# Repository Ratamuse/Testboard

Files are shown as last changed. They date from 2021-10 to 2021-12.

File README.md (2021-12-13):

## Testboard V2.2 ESP32

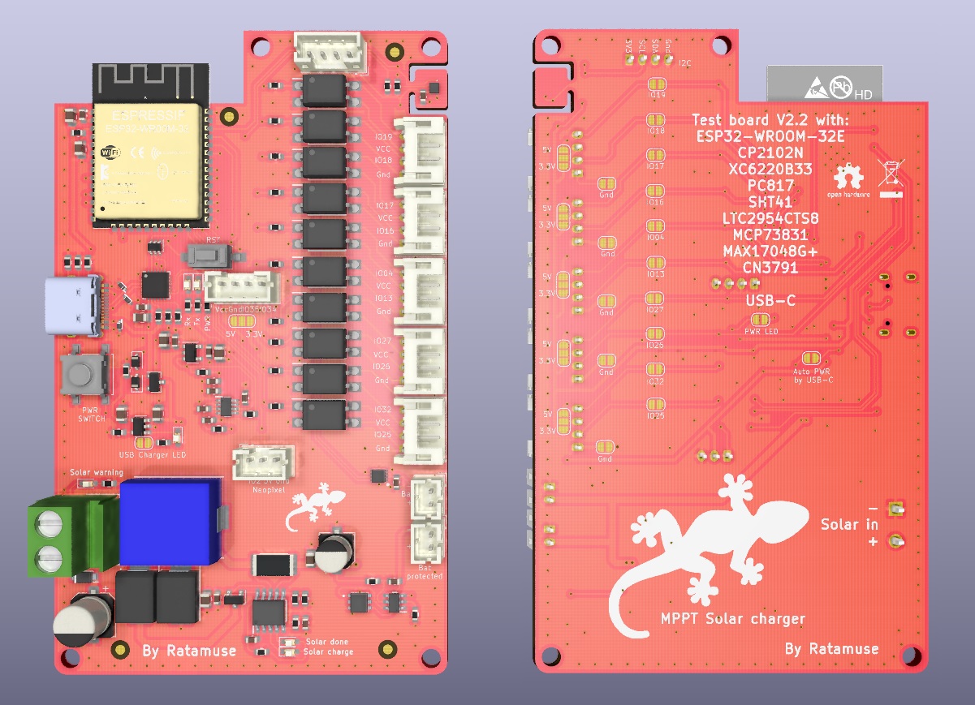
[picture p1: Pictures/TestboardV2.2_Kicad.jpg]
This is an image


## Carte multi-usage basée sur le module ESP-WROOM-32E:

- Connecteur USB-C

- Chargeur solaire MPPT basé sur la puce CN3791:  http://www.consonance-elec.com/pdf/datasheet/DSE-CN3791.pdf

- Connecteur batterie JST-PH 2mm avec protection (surcharge ou décharge profonde)

- Connecteur batterie JST-PH 2mm sans protection (pour batterie déjà protégée)

- Bouton on/off LTC2954 avec interrupt sur µP (On/Off de l'ESP32 et GPIO de l'interrupt utilisable pour des actions): https://www.analog.com/media/en/technical-documentation/data-sheets/2954fb.pdf

- Capteur température/humidité SHT41: https://www.sensirion.com/fileadmin/user_upload/customers/sensirion/Dokumente/2_Humidity_Sensors/Datasheets/Sensirion_Humidity_Sensors_SHT4x_Datasheet.pdf
- 10 optocoupleurs pour interrupteurs à contacts secs (pour domotiser volets roulants, télécommandes diverses) ou au choix 10 GPIO dispo avec au choix alim 3.3V ou "5V" (Vbat (entre 3.2 et 4.2V) ou Vbus (5V)) pour ajouter des modules.

- Chargeur Li-io/Li-Po MCP73831 via port USB-C

- Connecteur JST-PH 2mm (1x4) I2C

- Connecteur JST-PH 2mm (1x4) sur 2 GPIO + choix 3.3V ou 5V

- Connecteur JST-PH 2mm (1x3) sur 1 GPIO (que j'utilise pour piloter des leds neopixel)

Inspiration des travaux de Lilygo, Waveshare, GreatScoot.

Motivation et champs des possibles donnés par P. Demerliac et sa chaine Youtube Cyrob: https://www.youtube.com/channel/UC5QPFDZ3Y4ylkkGJc6Y1OOA  

Initiation à la bricole par P. W. Trainer

Prochaine étape, améliorer le hardaware du GNUVario-E

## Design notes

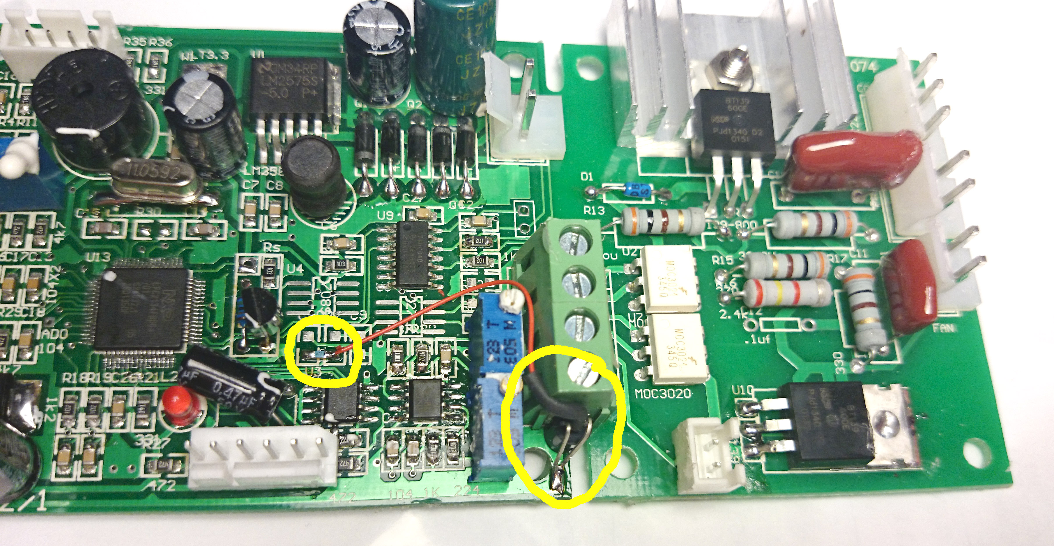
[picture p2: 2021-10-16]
3D/tempsensor-mod.jpg

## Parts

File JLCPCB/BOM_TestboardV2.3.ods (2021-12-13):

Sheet: TestboardV2.2
Id | Référence | Boîtier | Quantit� | Désignation | Mouser | LCSC | Reste | Quantité | A commander
1 | J13 | TYPE-C-31-M-12 | 1 | USB_C_Receptacle_USB2.0 USB4105-GF-A | 640-USB4105-GF-A |  | 2 | 1 | 2 | VMPTT | 18
2 | D14,D4 | D_SOD-323 | 2 | D_Schottky | 757-CUS10F30H3F or BAT20JFILM |  | 6 | 2 | 4 | R3
3 | R28 | R_2512_6332Metric | 1 | 0,05 | 71-WSL2512R2200FEA |  | 2 | 1 |  | R4 | 10000
4 | R23 | R_0603_1608Metric | 1 | 120K | 660-RN73H1JTD1203B25 |  | 3 | 2
5 | R23 | R_0603_1608Metric | 1 | 140K | 660-RK73H1JTTD1403F |  | 9
6 | C26 | CP_Elec_5x5.4 | 1 | 10µF/35V | 667-EEE-1VA100SR |  | 22 | 1 |  | VMPPT=1,205x(1+R3/R4)
7 | L1 | INDPM138126X700N | 1 | 82µH/3A |  | C149533 | 12 | 1
8 | Q4 | FS8205 | 1 | FS8205 |  | C32254 | 7 | 1
9 | D7,D6,D5,D9,D10,D13, D15 | LED_0603_1608Metric_Castellated | 7 | LED | 720-LSQ976-NR-1 & 720-LTQ39GQ1S22515 & 720-KODELLS122A4850 |  | 9R, 4V, 6O | 7 |  | VMPPT/1,205-1=R3/R4
10 | R22,R21,R14,R11,R10,R9,R8,R7,R6,R5,R4,R3,R2,R30,R29 | R_0603_1608Metric | 15 | 1K | 279-CRGCQ0603F1K0 |  | 46 | 15
11 | C3,C1 | C_0805_2012Metric | 2 | 22µF | 81-GRM219R61C226ME1K |  | 14 | 2 |  | (VMPPT/1,205-1)xR4
12 | D3,D2,D1 | SODFL1406X65N | 3 | SP1003-01DTG | 576-SP1003-01DTG |  | 5 | 3
13 | U12 | QFN-24-1EP_4x4mm_P0.5mm_EP2.6x2.6mm | 1 | CP2102N-A02-GQFN24 | 634-CP2102NA02QFN24R |  | 2 | 1 |  | #RÉF !
14 | IC2 | SON50P200X200X80-9N-D | 1 | MAX17048G+ | 700-MAX17048G+T10 |  | 24 | 1
15 | U1 | ESP32WROOM32EM113EH2800PH3Q0 | 1 | ESP32-WROOM-32E | 356-ESP32WRM32E128PH |  | 8 | 1
16 | C18,C12,C11,C9,C7,C2,C5,C27, C15 | C_0603_1608Metric | 9 | 0.1µF | 81-GCJ188R71C104KA1D |  | 41 | 10
17 | Q1 | SOT-363_SC-70-6 | 1 | UMH3N | 755-UMH3NTN |  | 7 | 1
18 | R17,R16 | R_0603_1608Metric | 2 | 2.2K | 279-CRGCQ0603F2K2 |  | 77 | 2
19 | IC1 | BME680 | 1 | BME680 | 262-BME680 |  | 0 | 1
20 | C13,C4 | C_0603_1608Metric | 2 | 1µF | 81-GCM188R71C105KA4J |  | 28 | 2
21 | U11,U10,U9,U8,U7,U6,U5,U4,U3,U2 | SOP254P960X420-4N | 10 | PC817 | 852-PC81710NIP1B |  | 8 | 10
22 | SW1,SW4 | PTS636SL43SMTRLFS | 2 | SW_Push | 611-PTS636SL43SMTRLF |  | 6 | 2
23 | R13 | R_0603_1608Metric | 1 | 47.5k | 755-SFR03EZPF4752 |  | 5 | 1
24 | R12 | R_0603_1608Metric | 1 | 22.1K | 660-RK73H1JTTDD2212F |  | 5 | 1
25 | R1,R19,R15,R27 | R_0603_1608Metric | 4 | 10K | 660-RN73H1JT1002F100 |  | 8 | 3
26 | U13 | SOT-23-5 | 1 | XC6220B331MR | 865-XC6220B331MR-G |  |  | 1
27 | C6,C16,C17 | C_0805Metric | 3 | 4.7µF | 81-GCM21BR71C475KA3L |  | 11 | 3
28 | Q2 | SOT-23 | 1 | DMG2301L | 621-DMG2301L-7 |  | ? | 1
29 | R18,R25,R35 | R_0603_1608Metric | 3 | 2K | 71-RCS06032K00FKEA |  | 12 | 3
30 | R20 | R_0603_1608Metric | 1 | 330 | 603-RE0603FRE07330RL |  | 11 | 1
31 | U15 | SOT-23-5 | 1 | MCP73831-2-OT | hors stock |  | 10 | 1
32 | C8,C10 | C_0603_1608Metric | 2 | 0,150µF | 80-C0603C154J4R |  | 4 | 2
33 | C8,C10 | C_0603_1608Metric | 2 | 0,330µF | 80-C0603C334J4R |  | 10
34 | C19 | CP_Elec_6.3x7.7 | 1 | 100µF/35V | 667-EEE-1VA101UP |  | 1 | 1
35 | C22 | C_0603_1608Metric | 1 | 220nF | 81-GCM188R71H224KA4J |  | 6 | 1
36 | C25 | C_0805_2012Metric | 1 | 10µF | 81-GCM21BM8EE106KE8L |  | 4 | 1
37 | D8 | SODFL3616X98N | 1 | MBR230LSFT1G | 755-RB060MM-30TFTR |  | 2 | 1
38 | D11,D12 | DIOM8059X256N | 2 | SS34 |  |  | 4 | 2
39 | IC3 | SOT65P280X100-8N | 1 | LTC2954CTS8-1#TRMPBF | 584-C2954CTS8-1TMPF |  | 3 | 1
40 | IC4 | SOP100P600X175-10N | 1 | CN3791 |  | C154992 | 10 | 1
41 | Q3 | SOT-23 | 1 | AO3401A |  | C306862 | 25 | 1
42 | Q5 | SOT95P280X125-3N | 1 | AO3400 |  | C332101 | 8 | 1
43 | R24 | R_0603_1608Metric | 1 | 120 | 660-RN73H1JT1200D100 |  | 2 | 1
44 | R31 | R_0603_1608Metric | 1 | 100 | 660-RN73H1JTD1000F25 |  | 2 | 1
45 | R32 | R_0603_1608Metric | 1 | 1.2K | 660-RN73H1JTD1201B25 |  | 2 | 1
46 | SW2 | SW_SPST_B3S-1000 | 1 | SW_Push | 653-B3S-1000 |  | 4 | 1
47 | C14 | C_0603_1608Metric | 1 | 470nF/50V | 810-C1608X7R1H474K |  | 7 | 1
48 | IC5 | SOT95P280X145-6N | 1 | FS312F-G |  | C82736 | 7 | 1
49 | R26 | R_0603_1608Metric | 1 | 1M | 755-KTR03EZPJ105 |  | 2 | 1
50 | R33,R34, R36 | R_0603_1608Metric | 3 | 5.1K | 660-RN73H1JTD5101B25 |  | 5 | 3
51 | R36 bis | R_0603_1608Metric | 1 | 0R | 71-RCS06030000Z0EA |  | 10 | 1
52 | C21 | C_0805Metric | 1 | 4,7µF/50V | 81-GRT21BR61H475KE3L |  | 2
53 | C23 | C_0603_1608Metric | 1 | 0,1µF/50V | 81-GCJ188R71H104KA2D |  | 7
54 | R37 | R_0603_1608Metric | 1 | 100K | 660-RN73H1JT1200D100 |  |  | 1

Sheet: TestboardV2.2_2
 | Id | Référence | Boîtier | Quantit� | Désignation | Mouser | Open PNP | LCSC | Reste | Quantité | DIGIKEY
1 | 16 | C18,C12,C11,C9,C7,C2,C5,C27, C15 | C_0603_1608Metric | 9 | 0.1µF | 81-GCJ188R71C104KA1D | ok |  | 41 | 10
2 | 20 | C13,C4 | C_0603_1608Metric | 2 | 1µF | 81-GCM188R71C105KA4J | ok |  | 28 | 2
3 | 35 | C22 | C_0603_1608Metric | 1 | 220nF/50V | 81-GCM188R71H224KA4J | ok |  | 6 | 1
4 | 47 | C14 | C_0603_1608Metric | 1 | 470nF/50V | 810-C1608X7R1H474K | ok |  | 7 | 1 |  | (VMPPT/1,205-1)xR4
5 | 50 | R33,R34, R36 | R_0603_1608Metric | 3 | 5.1K | 660-RN73H1JTD5101B25 | ok |  | 5 | 3
6 | 49 | R26 | R_0603_1608Metric | 1 | 1M | 755-KTR03EZPJ105 | ok |  | 2 | 1
7 | 30 | R20 | R_0603_1608Metric | 1 | 330 | 603-RE0603FRE07330RL | ok |  | 1 | 1
8 | 44 | R31 | R_0603_1608Metric | 1 | 100 | 660-RN73H1JTD1000F25 | ok |  | 2 | 1
9 | 45 | R32 | R_0603_1608Metric | 1 | 1.2K | 660-RN73H1JTD1201B25 | ok |  | 2 | 1
10 | 10 | R22,R21,R14,R11,R10,R9,R8,R7,R6,R5,R4,R3,R2,R30 | R_0603_1608Metric | 14 | 1K | 279-CRGCQ0603F1K0 | ok |  | 46 | 15
11 | 18 | R17,R16 | R_0603_1608Metric | 2 | 2.2K | 279-CRGCQ0603F2K2 | ok |  | 77 | 2
12 | 23 | R13 | R_0603_1608Metric | 1 | 47.5k | 755-SFR03EZPF4752 | ok |  | 5 | 1
13 | 24 | R12 | R_0603_1608Metric | 1 | 22.1K | 660-RK73H1JTTDD2212F | ok |  | 5 | 1
14 | 25 | R1,R19,R15,R27,R29,R25,R35 | R_0603_1608Metric | 5 | 10K | 660-RN73H1JT1002F100 | ok |  | 8 | 3
15 | 29 | R18 | R_0603_1608Metric | 1 | 2K | 71-RCS06032K00FKEA | ok |  | 1 | 1
16 | 53 | C23 | C_0603_1608Metric | 1 | 0,1µF/50V | 81-GCJ188R71H104KA2D |  |  | 7
17 | 32 | C8,C10 | C_0603_1608Metric | 2 | 0,150µF | 80-C0603C154J4R |  |  | 4
18 | 26 | U13 | SOT-23-5 | 1 | XC6220B331MR | 865-XC6220B331MR-G |  |  |  | 1 | 893-1133-1-ND
19 | 39 | IC3 | SOT65P280X100-8N | 1 | LTC2954CTS8-1#TRMPBF | 584-C2954CTS8-1TMPF |  |  |  | 1
 |  | GRM188R61C106KAALD |  | 0.800 | id R0603 | 100.0%

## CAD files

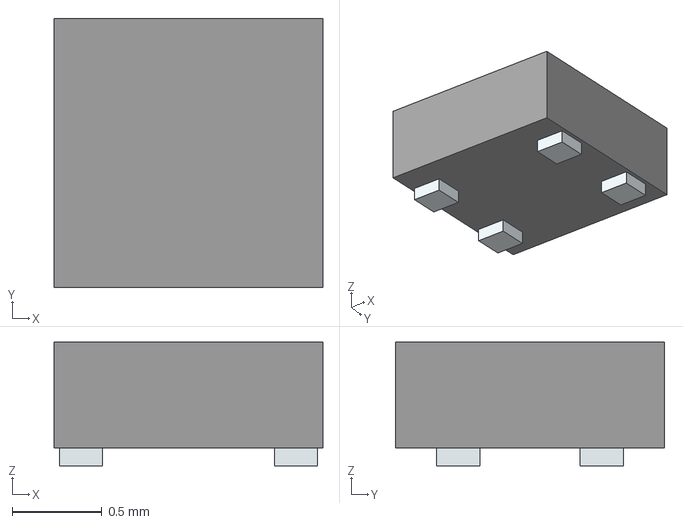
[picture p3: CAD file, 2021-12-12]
3D/SHT41-AD1B-R3.stp
1.50 x 1.50 x 0.69 mm
Pins

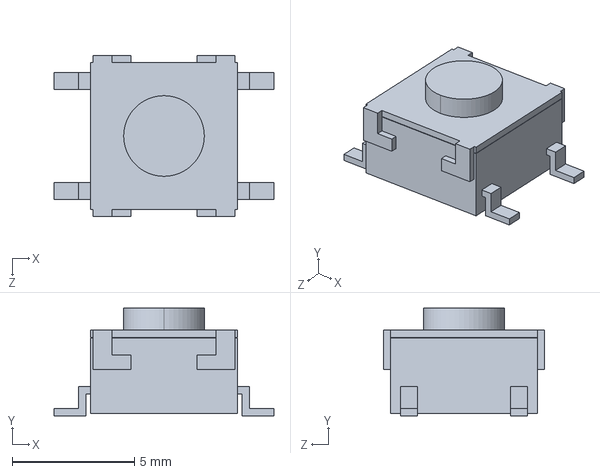
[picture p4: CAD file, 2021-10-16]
3D/B3S_100[].step
9.00 x 4.40 x 6.60 mm

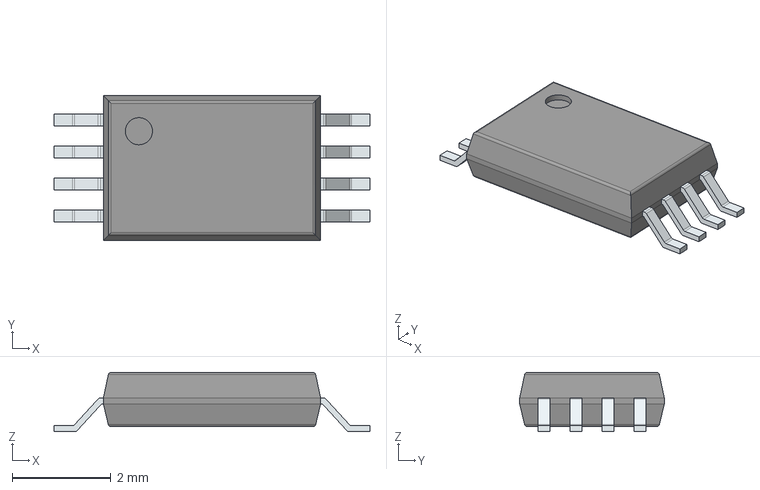
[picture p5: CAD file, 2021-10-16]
3D/FS8205A.stp
6.40 x 2.93 x 1.20 mm
PinsArrayLR

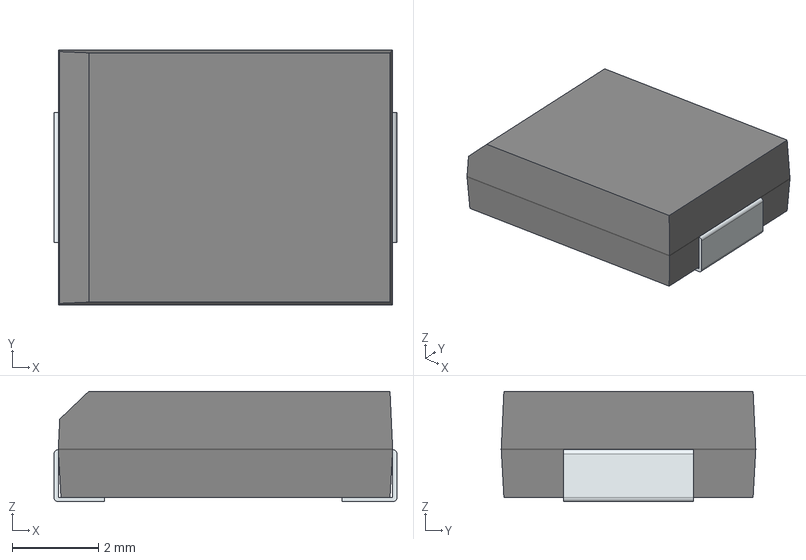
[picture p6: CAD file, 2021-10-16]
3D/SS34.stp
7.95 x 5.90 x 2.56 mm
FilletPin1
FilletPin2

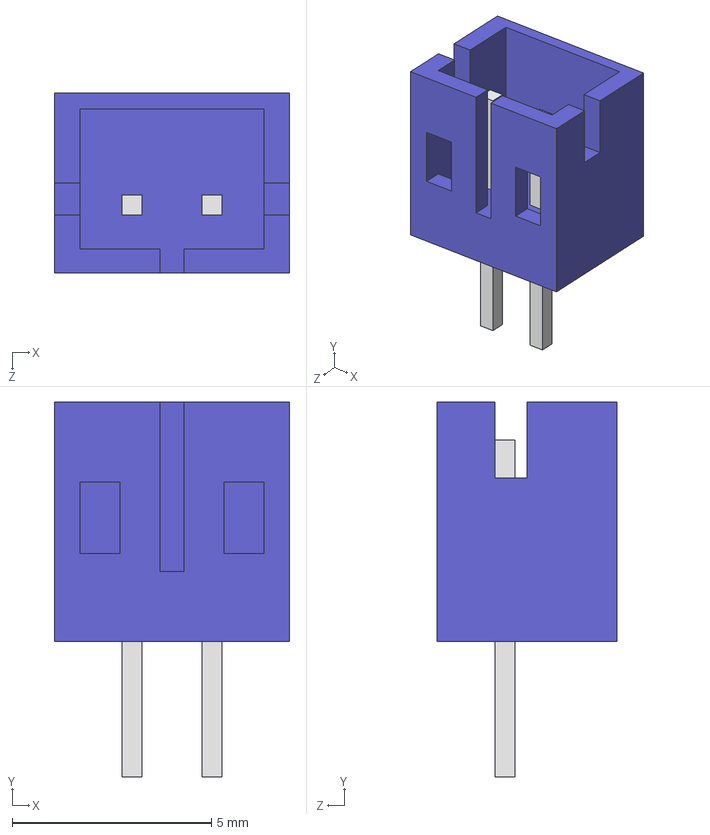
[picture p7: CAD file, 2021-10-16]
3D/B2B-PH-K-S.STEP
5.90 x 9.40 x 4.50 mm

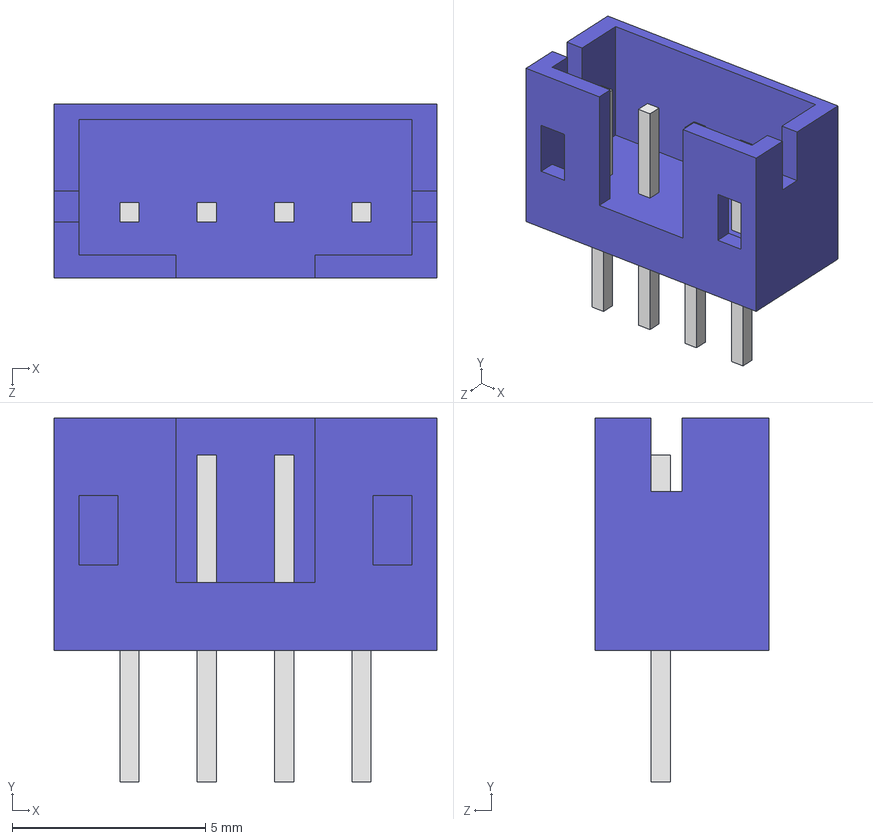
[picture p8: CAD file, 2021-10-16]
3D/B4B-PH-K-S.STEP
9.90 x 9.40 x 4.50 mm

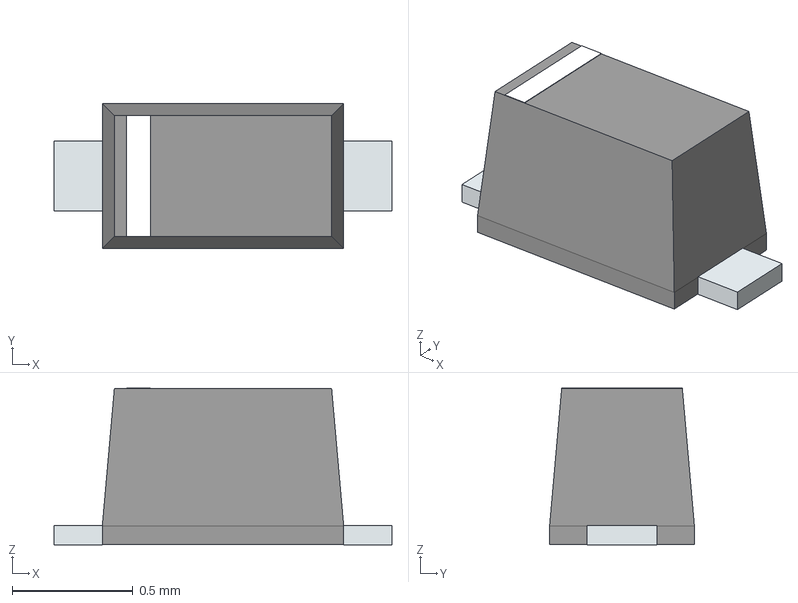
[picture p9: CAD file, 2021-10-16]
3D/SP1003-01DTG.stp
1.40 x 0.6 x 0.65 mm
PinKIdent
PinK
PinA

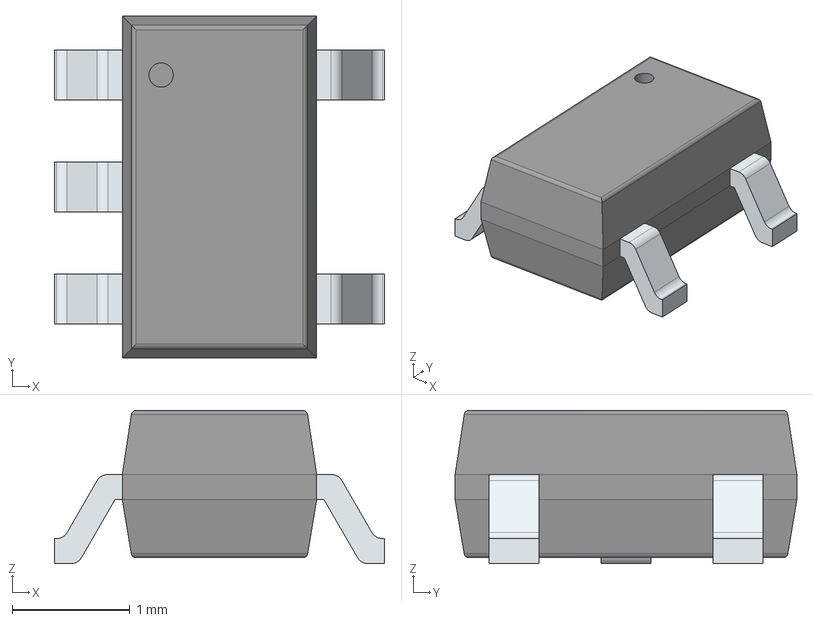
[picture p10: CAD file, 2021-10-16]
3D/XC6220B331MR-G.stp
2.80 x 2.90 x 1.30 mm
PinsArrayL
PinsArrayR

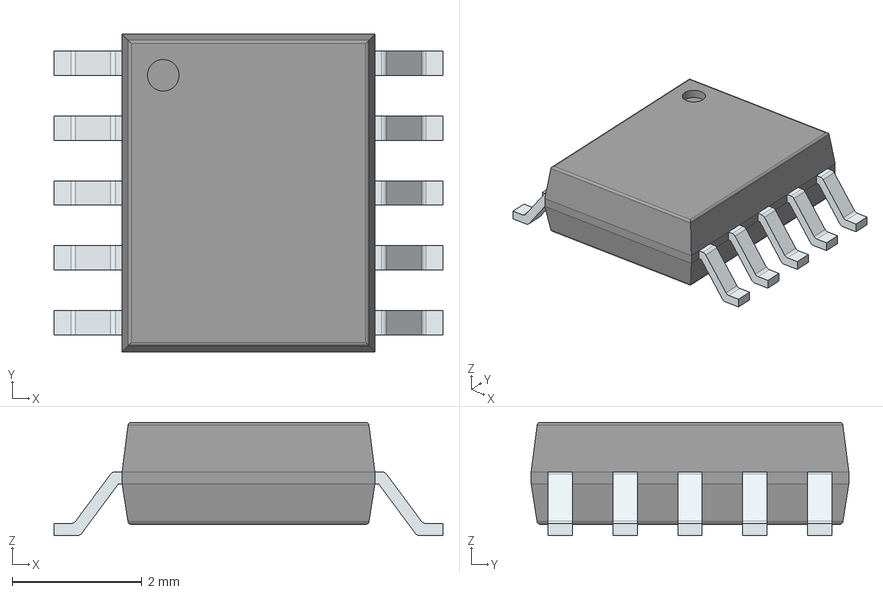
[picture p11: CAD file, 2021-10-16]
3D/CN3791.stp
6.00 x 4.90 x 1.75 mm
PinsArrayLR

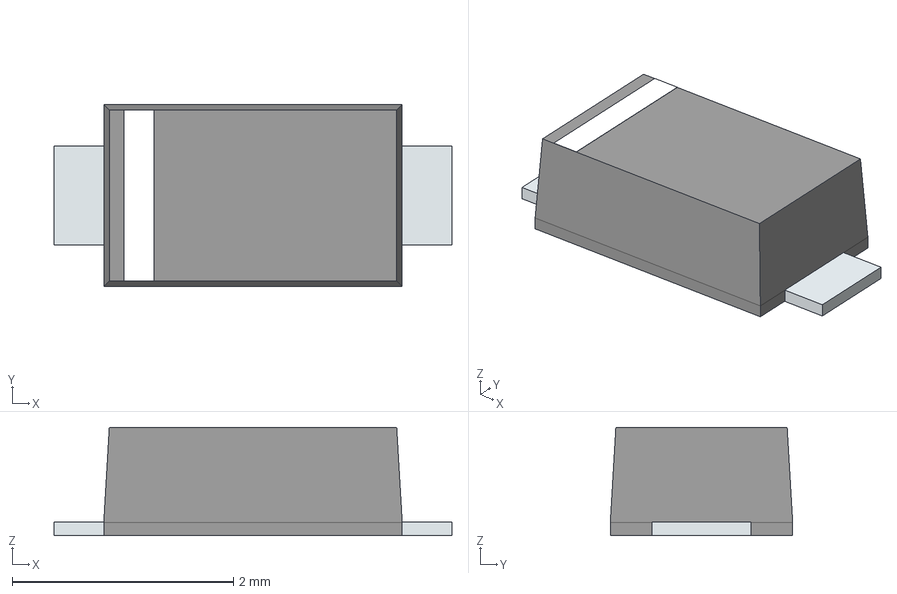
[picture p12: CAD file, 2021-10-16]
3D/MBR230LSFT1G.stp
3.60 x 1.65 x 0.98 mm
PinKIdent
PinK
PinA

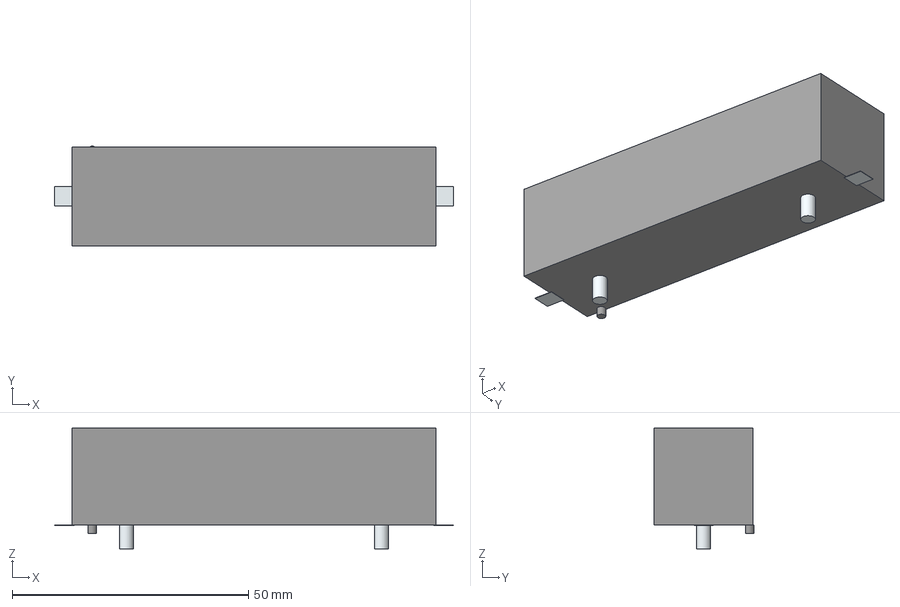
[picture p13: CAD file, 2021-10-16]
3D/12BHC186P1-GR.stp
84.5 x 21.1 x 25.6 mm
Pins
Lugs x 3
Leads x 3

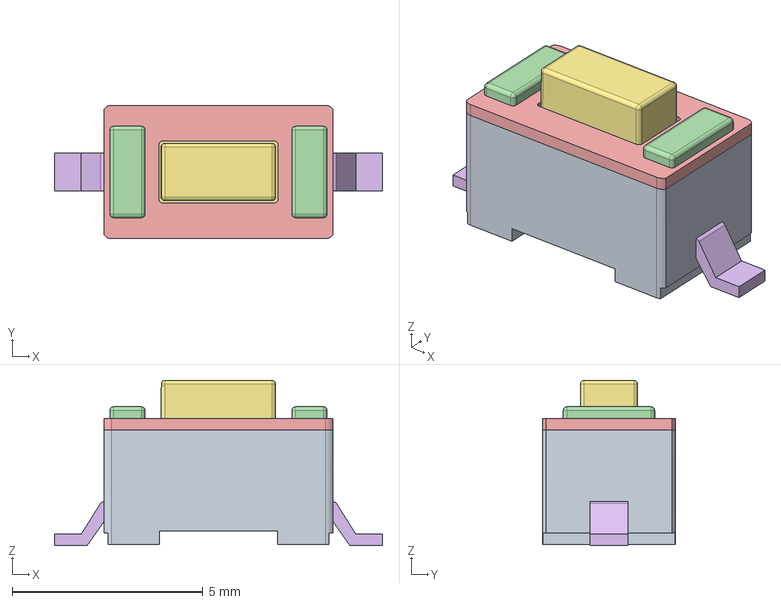
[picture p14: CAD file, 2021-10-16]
3D/PTS636SL43SMTRLFS.stp
8.60 x 3.50 x 4.33 mm

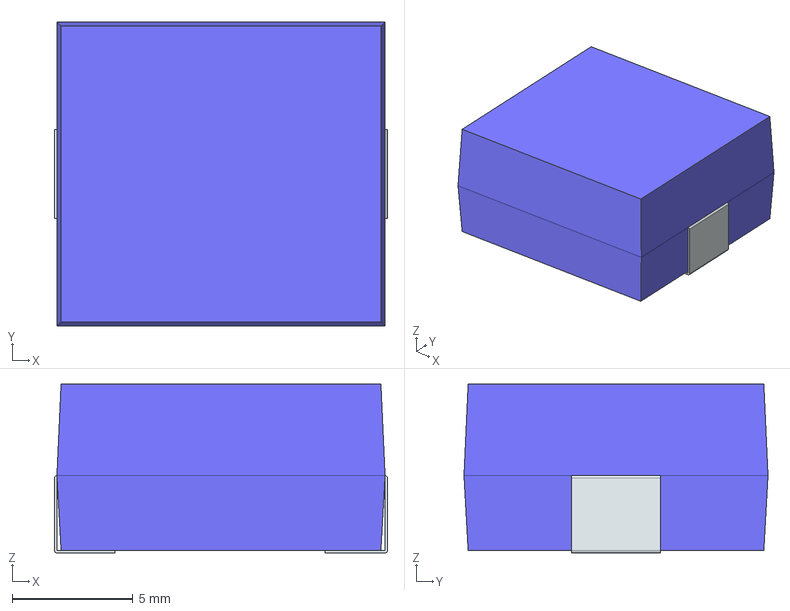
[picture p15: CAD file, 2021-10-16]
3D/SMMS1360-220M.stp
13.8 x 12.6 x 7.00 mm
FilletPin1
FilletPin2

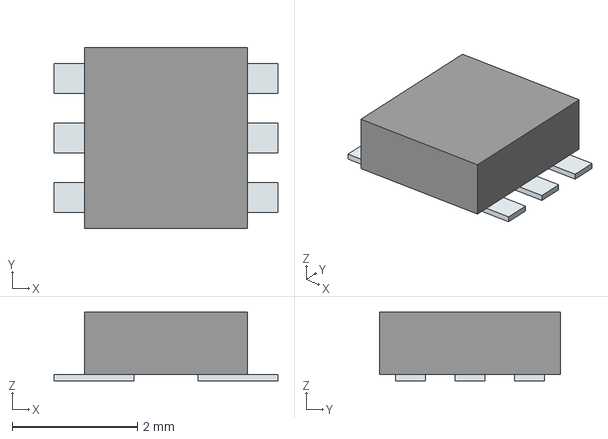
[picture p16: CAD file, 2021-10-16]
3D/FS8205.stp
3.58 x 2.90 x 1.10 mm
Pins

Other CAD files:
3D/DW01.stp
3D/B3B-PH-K-S.STEP
3D/AO3400.stp
3D/B4B-PH-SM4-TB.STEP
3D/1050170001.stp
3D/12BHC186P1-GR.stl
3D/1546215-2.stp
3D/691216710002.stp
3D/AO3400.stl
3D/BME680.step
3D/CN3791.stl
3D/DW01.stl
3D/ESP32-WROOM-32E_M113EH2800PH3Q0_.stp
3D/FS312F-G.stl
3D/FS312F-G.stp
3D/FS8205.stl
3D/FS8205A.stl
3D/LTC2954CTS8-1#TRMPBF.stl
3D/LTC2954CTS8-1#TRMPBF.stp
3D/MAX17048G+T10.stp
3D/MBR230LSFT1G.stl
3D/SS34.stl
3D/USB4105-GF-A--3DModel-STEP-56544.STEP
3D/User Library-PC817_Gullwing.STEP
3D/XC6220B331MR-G.stl

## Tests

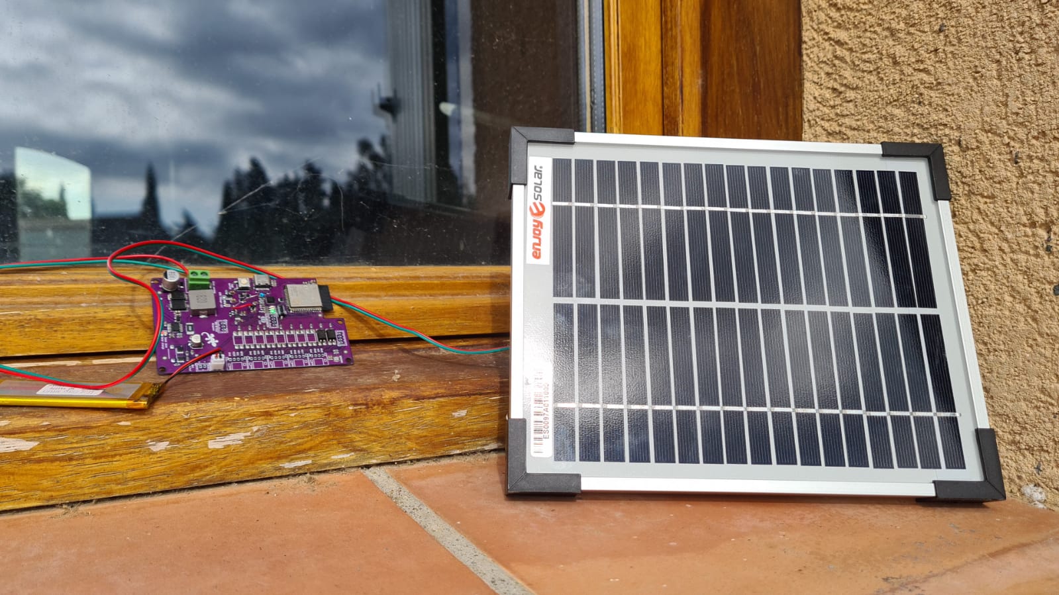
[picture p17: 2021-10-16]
Pictures/TestboardV2.2 solar charging.jpeg

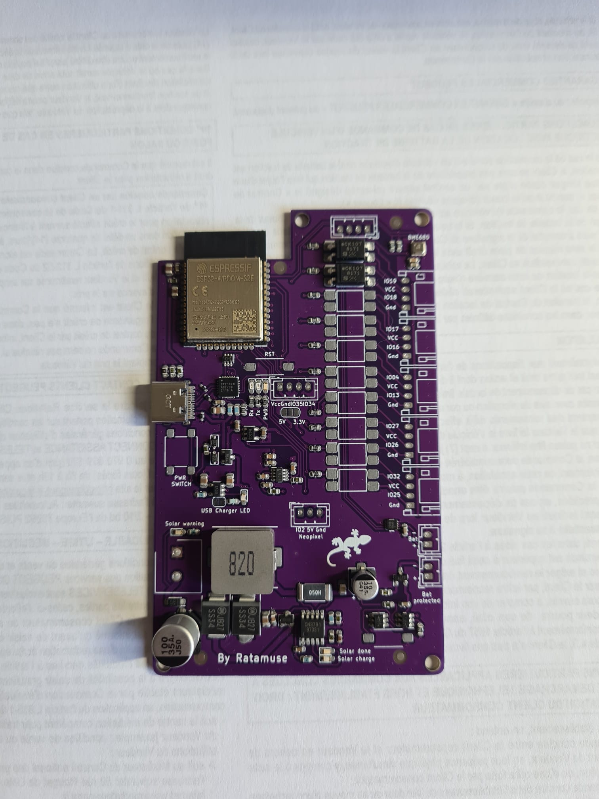
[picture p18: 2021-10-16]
Pictures/Testboard V2.2.jpeg

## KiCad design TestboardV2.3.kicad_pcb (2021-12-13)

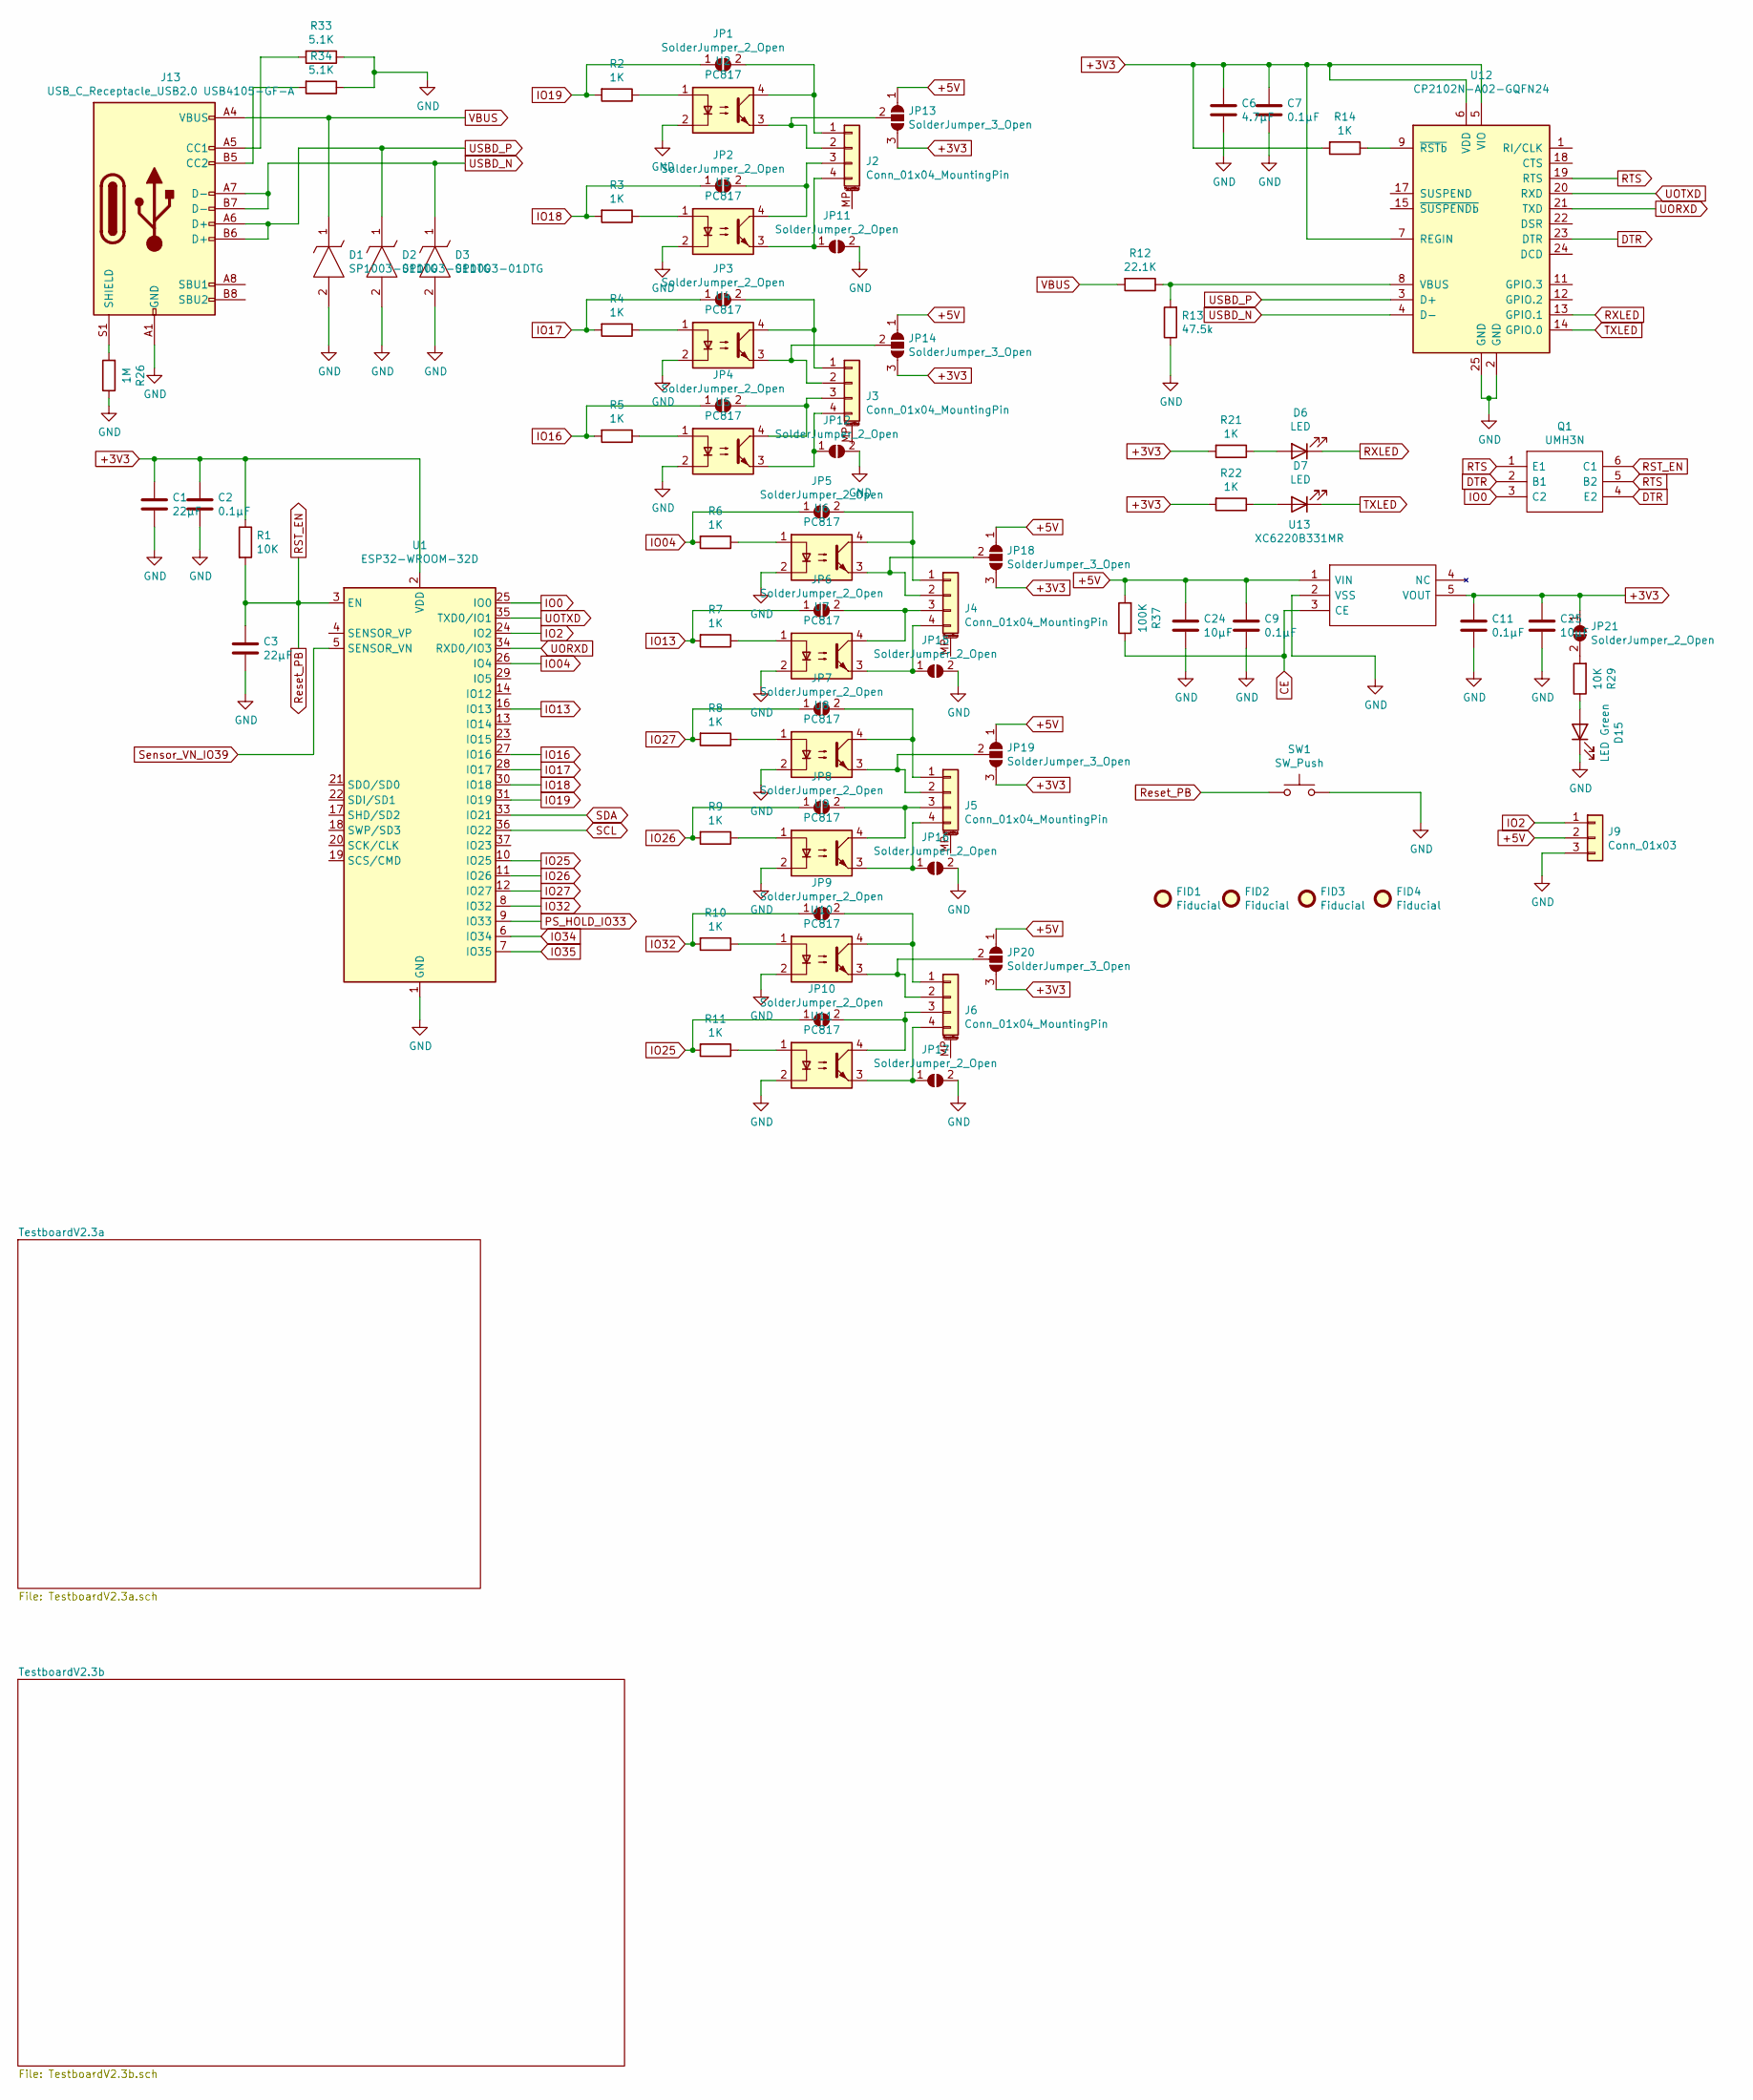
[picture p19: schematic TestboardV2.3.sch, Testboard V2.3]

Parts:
C1, C3: 22µF; C_0805_2012Metric
C2, C7, C9, C11: 0.1µF; C_0603_1608Metric
C6: 4.7µF; C_0805_2012Metric
C24, C25: 10µF; C_0805_2012Metric
D1, D2, D3: SP1003-01DTG; SODFL1406X65N; Manufacturer_Part_Number SP1003-01DTG; Mouser Part Number 576-SP1003-01DTG
D6, D7: LED; LED_0603_1608Metric_Castellated
D15: LED Green; LED_0603_1608Metric_Castellated
FID1, FID2, FID3, FID4: Fiducial; Fiducial_1.5mm_Mask3mm
J2, J3, J4, J5, J6: Conn_01x04_MountingPin; JST_PH_S4B-PH-K_1x04_P2.00mm_Horizontal_ratamuse
J9: Conn_01x03; JST_PH_B3B-PH-K_1x03_P2.00mm_Vertical
J13: USB_C_Receptacle_USB2.0 USB4105-GF-A; TYPE-C-31-M-12
JP1, JP2, JP3, JP4, JP5, JP6, JP7, JP8, JP9, JP10, JP11, JP12, JP15, JP16, JP17, JP21: SolderJumper_2_Open; SolderJumper-2_P1.3mm_Open_RoundedPad1.0x1.5mm
JP13, JP14, JP18, JP19, JP20: SolderJumper_3_Open; SolderJumper-3_P1.3mm_Open_RoundedPad1.0x1.5mm_NumberLabels
Q1: UMH3N; SOT-363_SC-70-6; Manufacturer_Part_Number UMH3N
R1, R29: 10K; R_0603_1608Metric
R2, R3, R4, R5, R6, R7, R8, R9, R10, R11, R14, R21, R22: 1K; R_0603_1608Metric
R12: 22.1K; R_0603_1608Metric
R13: 47.5k; R_0603_1608Metric
R26: 1M; R_0603_1608Metric
R33, R34: 5.1K; R_0603_1608Metric
R37: 100K; R_0603_1608Metric
SW1: SW_Push; PTS636SL43SMTRLFS
U1: ESP32-WROOM-32D; ESP32WROOM32EM113EH2800PH3Q0
U2, U3, U4, U5, U6, U7, U8, U9, U10, U11: PC817; SOP254P960X420-4N
U12: CP2102N-A02-GQFN24; QFN-24-1EP_4x4mm_P0.5mm_EP2.6x2.6mm
U13: XC6220B331MR; SOT-23-5

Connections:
+3V3: C1.1, C2.1, C6.1, C7.1, C11.1, C25.1, JP13.3 (B), JP14.3 (B), JP18.3 (B), JP19.3 (B), JP20.3 (B), JP21.1 (A), R1.1, R14.2, R21.2, R22.2, U1.2 (VDD), U12.5 (VIO), U12.6 (VDD), U12.7 (REGIN), U13.5 (VOUT); also elsewhere on the board
+5V: C9.1, C24.1, J9.2, JP13.1 (A), JP14.1 (A), JP18.1 (A), JP19.1 (A), JP20.1 (A), R37.2, U13.1 (VIN); also elsewhere on the board
CE: R37.1, U13.3 (CE); also elsewhere on the board
DTR: Q1.2 (B1), Q1.4 (E2), U12.23 (DTR)
GND: C1.2, C2.2, C3.2, C6.2, C7.2, C9.2, C11.2, C24.2, C25.2, D1.2, D2.2, D3.2, D15.1 (K), J9.3, J13.A1 (GND), J13.A12 (GND), J13.B1 (GND), J13.B12 (GND), JP11.2 (B), JP12.2 (B), JP15.2 (B), JP16.2 (B), JP17.2 (B), R13.1, R26.1, R33.1, R34.1, SW1.2, U1.1 (GND), U1.15 (GND), U1.38 (GND), U1.39 (GND), U2.2, U3.2, U4.2, U5.2, U6.2, U7.2, U8.2, U9.2, U10.2, U11.2, U12.2 (GND), U12.25 (GND), U13.2 (VSS); also elsewhere on the board
IO0: Q1.3 (C2), U1.25 (IO0)
IO2: J9.1, U1.24 (IO2)
IO04: JP5.1 (A), R6.2, U1.26 (IO4)
IO13: JP6.1 (A), R7.2, U1.16 (IO13)
IO16: JP4.1 (A), R5.2, U1.27 (IO16)
IO17: JP3.1 (A), R4.2, U1.28 (IO17)
IO18: JP2.1 (A), R3.2, U1.30 (IO18)
IO19: JP1.1 (A), R2.2, U1.31 (IO19)
IO25: JP10.1 (A), R11.2, U1.10 (IO25)
IO26: JP8.1 (A), R9.2, U1.11 (IO26)
IO27: JP7.1 (A), R8.2, U1.12 (IO27)
IO32: JP9.1 (A), R10.2, U1.8 (IO32)
IO34: U1.6 (IO34); also elsewhere on the board
IO35: U1.7 (IO35); also elsewhere on the board
unnamed: D6.2 (A), R21.1
unnamed: D7.2 (A), R22.1
unnamed: D15.2 (A), R29.1
unnamed: J2.1, JP1.2 (B), U2.4
unnamed: J2.2, JP13.2 (C), U2.3
unnamed: J2.3, JP2.2 (B), U3.4
unnamed: J2.4, JP11.1 (A), U3.3
unnamed: J3.1, JP3.2 (B), U4.4
unnamed: J3.2, JP14.2 (C), U4.3
unnamed: J3.3, JP4.2 (B), U5.4
unnamed: J3.4, JP12.1 (A), U5.3
unnamed: J4.1, JP5.2 (B), U6.4
unnamed: J4.2, JP18.2 (C), U6.3
unnamed: J4.3, JP6.2 (B), U7.4
unnamed: J4.4, JP15.1 (A), U7.3
unnamed: J5.1, JP7.2 (B), U8.4
unnamed: J5.2, JP19.2 (C), U8.3
unnamed: J5.3, JP8.2 (B), U9.4
unnamed: J5.4, JP16.1 (A), U9.3
unnamed: J6.1, JP9.2 (B), U10.4
unnamed: J6.2, JP20.2 (C), U10.3
unnamed: J6.3, JP10.2 (B), U11.4
unnamed: J6.4, JP17.1 (A), U11.3
unnamed: J13.A5 (CC1), R33.2
unnamed: J13.B5 (CC2), R34.2
unnamed: J13.S1 (SHIELD), R26.2
unnamed: JP21.2 (B), R29.2
unnamed: R2.1, U2.1
unnamed: R3.1, U3.1
unnamed: R4.1, U4.1
unnamed: R5.1, U5.1
unnamed: R6.1, U6.1
unnamed: R7.1, U7.1
unnamed: R8.1, U8.1
unnamed: R9.1, U9.1
unnamed: R10.1, U10.1
unnamed: R11.1, U11.1
unnamed: R12.1, R13.2, U12.8 (VBUS)
unnamed: R14.1, U12.9 (~RSTb)
PS_HOLD_IO33: U1.9 (IO33); also elsewhere on the board
RST_EN: C3.1, Q1.6 (C1), R1.2, SW1.1, U1.3 (EN)
RTS: Q1.1 (E1), Q1.5 (B2), U12.19 (RTS)
RXLED: D6.1 (K), U12.13 (GPIO.1)
SCL: U1.36 (IO22); also elsewhere on the board
SDA: U1.33 (IO21); also elsewhere on the board
Sensor_VN_IO39: U1.5 (SENSOR_VN); also elsewhere on the board
TXLED: D7.1 (K), U12.14 (GPIO.0)
UORXD: U1.34 (RXD0/IO3), U12.21 (TXD)
UOTXD: U1.35 (TXD0/IO1), U12.20 (RXD)
USBD_N: D3.1, J13.A7 (D-), J13.B7 (D-), U12.4 (D-)
USBD_P: D2.1, J13.A6 (D+), J13.B6 (D+), U12.3 (D+)
VBUS: D1.1, J13.A4 (VBUS), J13.A9 (VBUS), J13.B4 (VBUS), J13.B9 (VBUS), R12.2; also elsewhere on the board

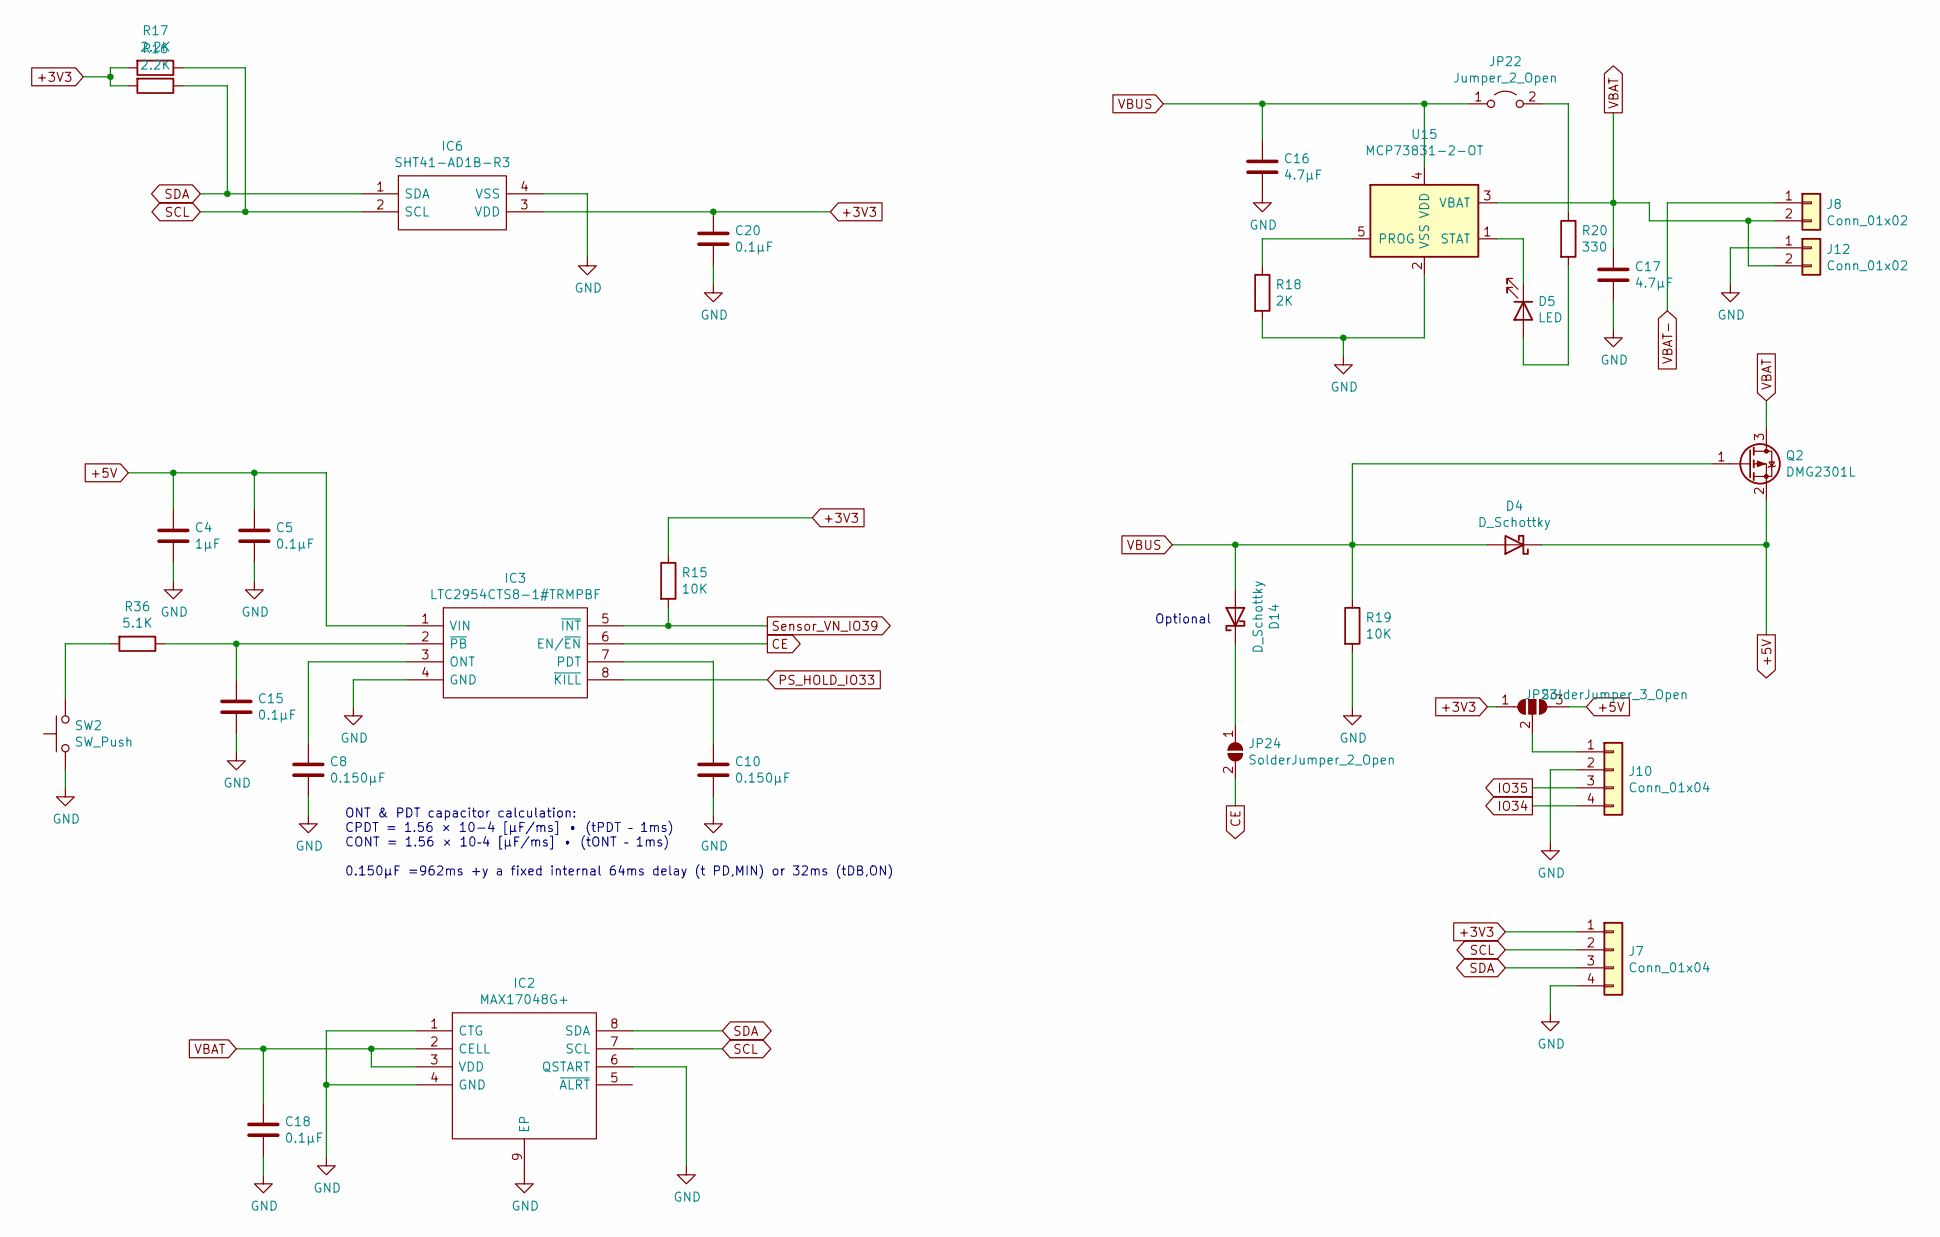
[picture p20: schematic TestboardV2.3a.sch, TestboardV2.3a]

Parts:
C4: 1µF; C_0603_1608Metric
C5, C15, C18, C20: 0.1µF; C_0603_1608Metric
C8, C10: 0.150µF; C_0603_1608Metric
C16, C17: 4.7µF; C_0805_2012Metric
D4, D14: D_Schottky; D_SOD-323
D5: LED; LED_0603_1608Metric_Castellated
IC2: MAX17048G+; SON50P200X200X80-9N-D; Manufacturer_Part_Number MAX17048G+; Mouser Part Number 700-MAX17048G+
IC3: LTC2954CTS8-1#TRMPBF; SOT65P280X100-8N; Manufacturer_Part_Number LTC2954CTS8-1#TRMPBF; Mouser Part Number 584-C2954CTS8-1TMPF
IC6: SHT41-AD1B-R3; SHT41AD1BR3; Manufacturer_Part_Number SHT41-AD1B-R3; Mouser Part Number 403-SHT41-AD1B-R3
J7, J10: Conn_01x04; JST_PH_B4B-PH-K_1x04_P2.00mm_Vertical
J8, J12: Conn_01x02; JST_PH_B2B-PH-K_1x02_P2.00mm_Vertical
JP22: Jumper_2_Open; SolderJumper-2_P1.3mm_Open_RoundedPad1.0x1.5mm
JP23: SolderJumper_3_Open; SolderJumper-3_P1.3mm_Open_RoundedPad1.0x1.5mm_NumberLabels
JP24: SolderJumper_2_Open; SolderJumper-2_P1.3mm_Open_RoundedPad1.0x1.5mm
Q2: DMG2301L; SOT-23
R15, R19: 10K; R_0603_1608Metric
R16, R17: 2.2K; R_0603_1608Metric
R18: 2K; R_0603_1608Metric
R20: 330; R_0603_1608Metric
R36: 5.1K; R_0603_1608Metric
SW2: SW_Push; SW_SPST_B3S-1000
U15: MCP73831-2-OT; SOT-23-5

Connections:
+3V3: C20.1, IC6.3 (VDD), J7.1, JP23.1 (A), R15.1, R16.2, R17.2; also elsewhere on the board
+5V: C4.1, C5.1, D4.1 (K), IC3.1 (VIN), JP23.3 (B), Q2.2 (S); also elsewhere on the board
CE: IC3.6 (EN/~EN), JP24.2 (B); also elsewhere on the board
GND: C4.2, C5.2, C8.2, C10.2, C15.2, C16.2, C17.2, C18.2, C20.2, IC2.1 (CTG), IC2.4 (GND), IC2.6 (QSTART), IC2.9 (EP), IC3.4 (GND), IC6.4 (VSS), J7.4, J10.2, J12.1, R18.2, R19.2, SW2.1, U15.2 (VSS); also elsewhere on the board
IO34: J10.4; also elsewhere on the board
IO35: J10.3; also elsewhere on the board
unnamed: C8.1, IC3.3 (ONT)
unnamed: C10.1, IC3.7 (PDT)
unnamed: C15.1, IC3.2 (~PB), R36.1
unnamed: D5.1 (K), U15.1 (STAT)
unnamed: D5.2 (A), R20.2
unnamed: D14.1 (K), JP24.1 (A)
unnamed: J10.1, JP23.2 (C)
unnamed: JP22.2 (B), R20.1
unnamed: R18.1, U15.5 (PROG)
unnamed: R36.2, SW2.2
PS_HOLD_IO33: IC3.8 (~KILL); also elsewhere on the board
SCL: IC2.7 (SCL), IC6.2 (SCL), J7.2, R17.1; also elsewhere on the board
SDA: IC2.8 (SDA), IC6.1 (SDA), J7.3, R16.1; also elsewhere on the board
Sensor_VN_IO39: IC3.5 (~INT), R15.2; also elsewhere on the board
VBAT: C17.1, C18.1, IC2.2 (CELL), IC2.3 (VDD), J8.2, J12.2, Q2.3 (D), U15.3 (VBAT); also elsewhere on the board
VBAT-: J8.1; also elsewhere on the board
VBUS: C16.1, D4.2 (A), D14.2 (A), JP22.1 (A), Q2.1 (G), R19.1, U15.4 (VDD); also elsewhere on the board

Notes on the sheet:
Optional
ONT & PDT capacitor calculation: CPDT = 1.56 × 10-4 [μF/ms] • (tPDT – 1ms) CONT = 1.56 × 10–4 [μF/ms] • (tONT – 1ms) 0.150µF =962ms +y a fixed internal 64ms delay (t PD,MIN) or 32ms (tDB,ON)

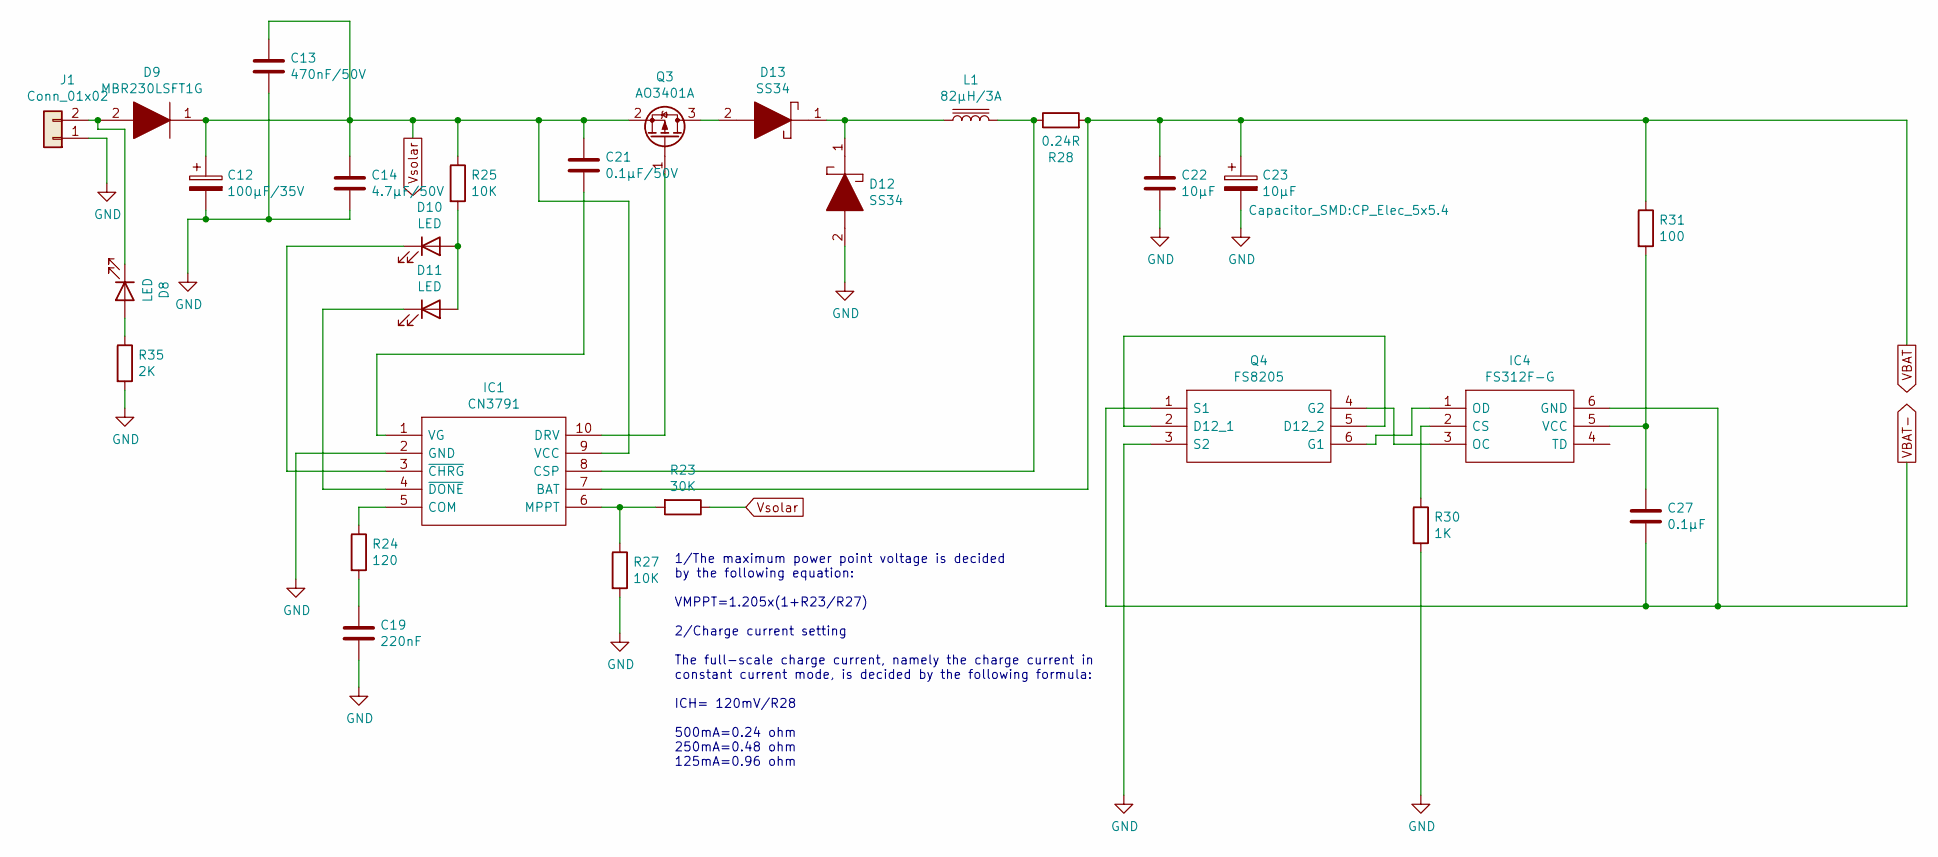
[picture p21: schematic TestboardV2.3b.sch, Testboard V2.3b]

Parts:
C12: 100µF/35V; CP_Elec_6.3x7.7
C13: 470nF/50V; C_0603_1608Metric
C14: 4.7µF/50V; C_0805_2012Metric
C19: 220nF; C_0603_1608Metric
C21: 0.1µF/50V; C_0603_1608Metric
C22: 10µF; C_0805_2012Metric
C23: 10µF; CP_Elec_5x5.4
C27: 0.1µF; C_0603_1608Metric
D8, D10, D11: LED; LED_0603_1608Metric_Castellated
D9: MBR230LSFT1G; SODFL3616X98N; Manufacturer_Part_Number MBR230LSFT1G; Mouser Part Number 863-MBR230LSFT1G
D12, D13: SS34; DIOM8059X256N; Manufacturer_Part_Number SS34; Mouser Part Number 512-SS34
IC1: CN3791; SOP100P600X175-10N; Manufacturer_Part_Number CN3791
IC4: FS312F-G; SOT95P280X145-6N; Manufacturer_Part_Number FS312F-G
J1: Conn_01x02; SHDR2W90P0X500_1X2_1060X980X1380P
L1: 82µH/3A; INDPM138126X700N
Q3: AO3401A; SOT-23
Q4: FS8205; Manufacturer_Part_Number FS8205
R23: 30K; R_0603_1608Metric
R24: 120; R_0603_1608Metric
R25, R27: 10K; R_0603_1608Metric
R28: 0.24R; R_2512_6332Metric
R30: 1K; R_0603_1608Metric
R31: 100; R_0603_1608Metric
R35: 2K; R_0603_1608Metric

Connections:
GND: C12.2, C13.2, C14.2, C19.2, C22.2, C23.2, D12.2, IC1.2 (GND), J1.1, Q4.3 (S2), R27.2, R30.2, R35.2; also elsewhere on the board
unnamed: C19.1, R24.2
unnamed: C21.2, IC1.1 (VG)
unnamed: C27.1, IC4.5 (VCC), R31.2
unnamed: D8.1 (K), D9.2, J1.2
unnamed: D8.2 (A), R35.1
unnamed: D10.1 (K), IC1.3 (~CHRG)
unnamed: D10.2 (A), D11.2 (A), R25.2
unnamed: D11.1 (K), IC1.4 (~DONE)
unnamed: D12.1, D13.1, L1.1
unnamed: D13.2, Q3.3 (D)
unnamed: IC1.5 (COM), R24.1
unnamed: IC1.6 (MPPT), R23.2, R27.1
unnamed: IC1.8 (CSP), L1.2, R28.1
unnamed: IC1.10 (DRV), Q3.1 (G)
unnamed: IC4.1 (OD), Q4.6 (G1)
unnamed: IC4.2 (CS), R30.1
unnamed: IC4.3 (OC), Q4.4 (G2)
unnamed: Q4.2 (D12_1), Q4.5 (D12_2)
VBAT: C22.1, C23.1, IC1.7 (BAT), R28.2, R31.1; also elsewhere on the board
VBAT-: C27.2, IC4.6 (GND), Q4.1 (S1); also elsewhere on the board
Vsolar: C12.1, C13.1, C14.1, C21.1, D9.1, IC1.9 (VCC), Q3.2 (S), R23.1, R25.1

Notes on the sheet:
1/The maximum power point voltage is decided by the following equation: VMPPT=1.205x(1+R23/R27) 2/Charge current setting The full-scale charge current, namely the charge current in constant current mode, is decided by the following formula: ICH= 120mV/R28 500mA=0.24 ohm 250mA=0.48 ohm 125mA=0.96 ohm

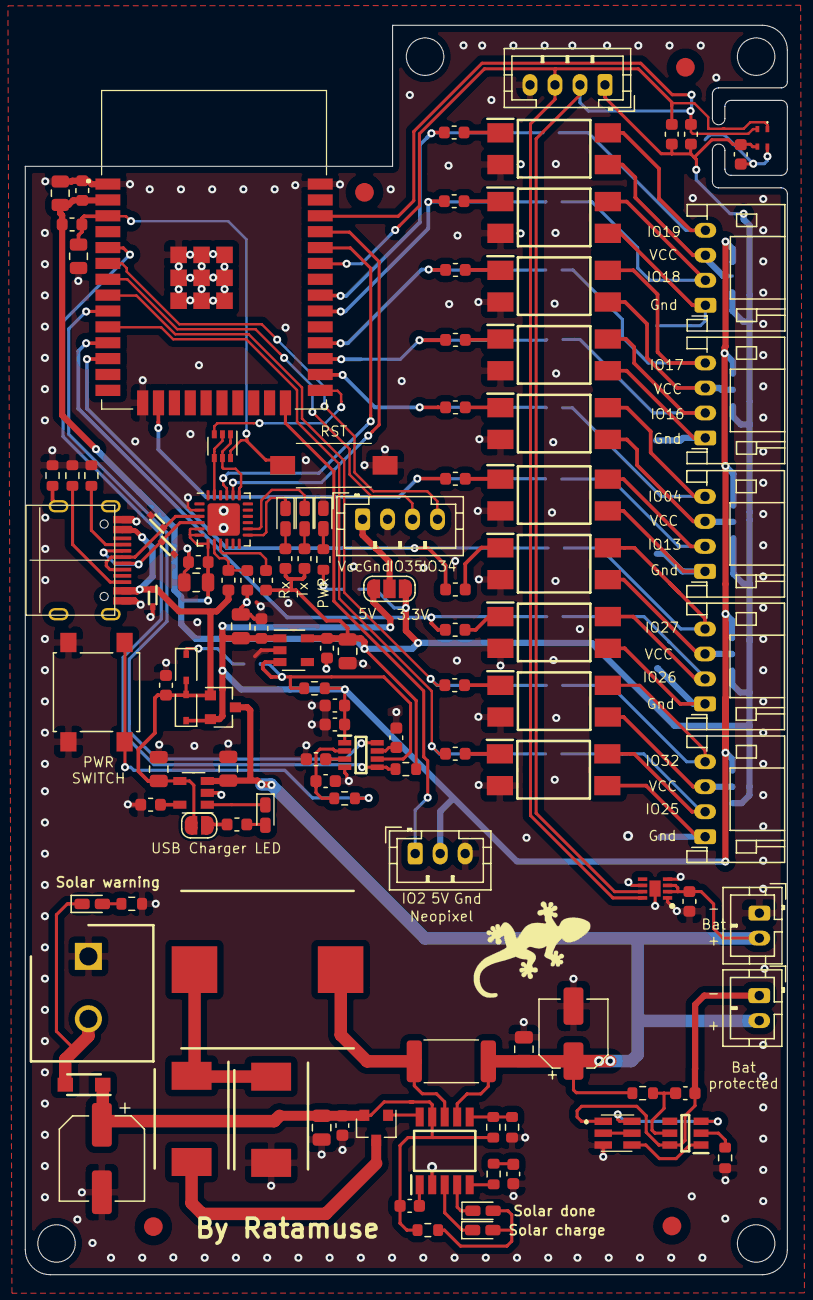
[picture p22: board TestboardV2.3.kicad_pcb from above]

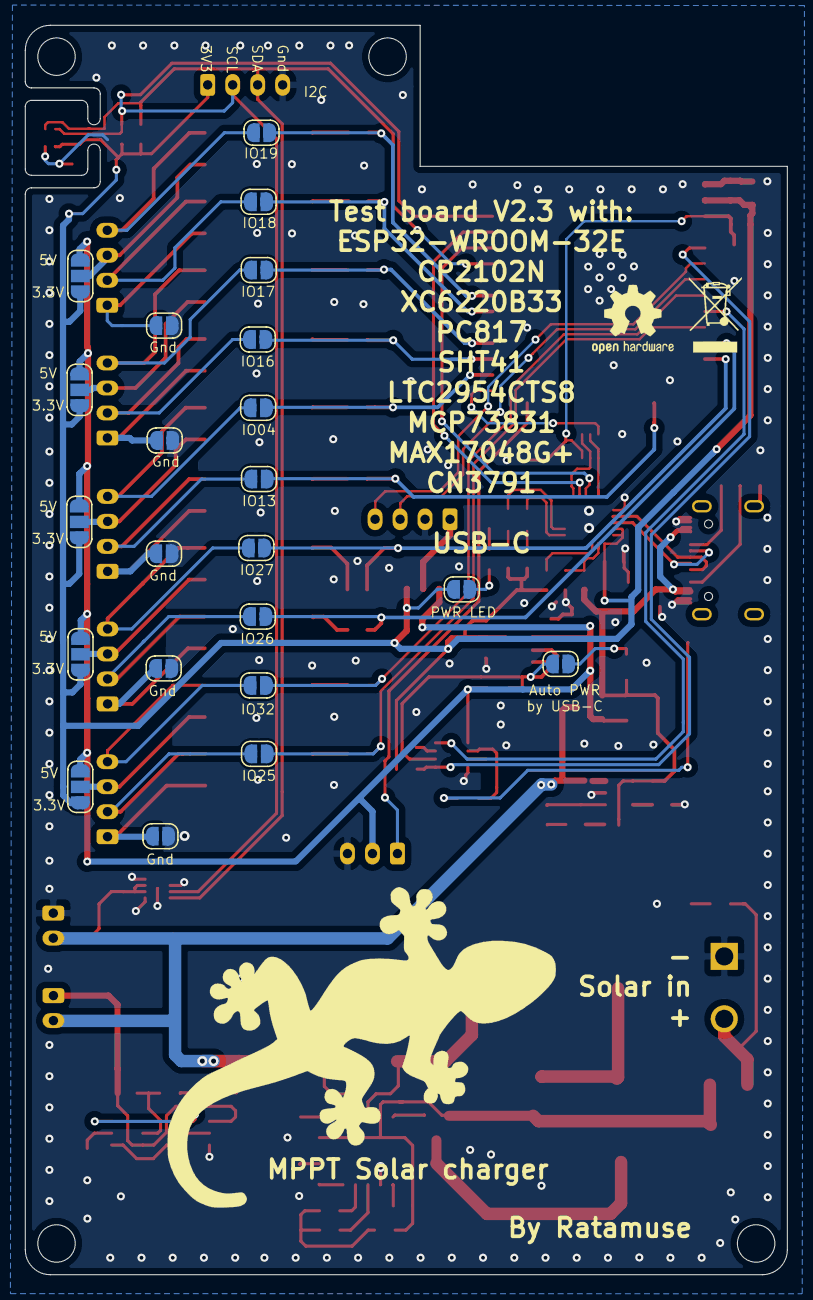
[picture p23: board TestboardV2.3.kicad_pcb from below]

Board: 2 copper layers, 61.0 x 100.0 mm, 143 parts (22 on the bottom side), 102 nets.

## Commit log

2021-10-16 Folder update
    [1050170001.stp, 12BHC186P1-GR.stl, 12BHC186P1-GR.stp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]
2021-10-16 Ajout BOM
    [BOM_TestboardV2.2.ods]
2021-10-18 BOM updated Add comments on PCB drawing (solar charger)
    [BOM_TestboardV2.2.ods, TestboardV2.2.ods]
2021-10-28 Added LDO CE Pullup. JLCPCB files updated
    [1546215-2.stp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]
2021-12-12 Testboard V2.3
    [BOM_TestboardV2.2.ods, SHT41-AD1B-R3.stp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]
2021-12-13 Gnd pad correction
    [BOM_TestboardV2.2.ods, BOM_TestboardV2.3.ods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]
2021-12-13 serigraphy correction
    [TestboardV2.3-B_Cu.gbr, TestboardV2.3-B_Mask.gbr, TestboardV2.3-B_Paste.gbr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]

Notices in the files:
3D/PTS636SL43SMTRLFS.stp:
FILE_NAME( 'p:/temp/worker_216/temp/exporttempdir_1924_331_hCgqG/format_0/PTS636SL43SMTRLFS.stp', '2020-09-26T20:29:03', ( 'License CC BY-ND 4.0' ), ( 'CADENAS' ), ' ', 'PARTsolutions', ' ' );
